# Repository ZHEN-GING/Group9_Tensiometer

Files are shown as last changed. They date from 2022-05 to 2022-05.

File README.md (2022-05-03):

# Group9_Tensiometer
 
1. We use TinkerCad to creat and edit a new clamp modeul, export to STL file so we could slice it with pursaSlice. Then , export it to SD card as G-code, so the 3d printer can print it directly. Here is our module: https://www.tinkercad.com/things/bVDQzztE6Tl-copy-of-surprising-amur-curcan/edit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 （need to log in）

2. System Parts: 
Steel gearing fit with servo motor(25T) ： https://www.amazon.com/dp/B07YWKMQ1M?ref=ppx_pop_mob_ap_share

LCD Screen： https://www.amazon.com/dp/B07S7PJYM6?ref=ppx_pop_mob_ap_share

ESP-12P： https://www.amazon.com/HiLetgo-Internet-Development-Wireless-Micropython/dp/B010O1G1ES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

  Servo Motor： https://www.amazon.com/dp/B07Z3VGZNP?ref=ppx_pop_mob_ap_share

3. 
For Arduino library:
<HX711.h>：https://github.com/bogde/HX711
<ESP8266WiFi.h> ：https://github.com/esp8266/Arduino/tree/master/libraries/ESP8266WiFi

For Blynk: https://www.youtube.com/watch?v=EYrEjC3QEew

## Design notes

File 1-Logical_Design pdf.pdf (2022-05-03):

PP-2017 V2.1

ANALYSIS & LOGICAL DESIGN | 1

# Logical Design Proposal Group Number 9

Gavin Haar, Liuhuan Zhang, Zhen Xu

Activity Report

Abstract—The paper “Fabrication of an Economical Arduino-based Uniaxial Tensile Tester” by Julien H. Arriza- balaga,† Aaron D. Simmons,‡ and Matthias U. Nollert et al. details how the team designed and constructed a tensiometer, which is a machine which measures the tensile strength of various materials, at a reduced cost compared to a professional model. Their model worked well, especially considering their low budget of only 100 dollars. However, their model has some shortcomings. Because the data collected before the improvement was not good. It has to do with the accuracy of the code, the accuracy of the components, the friction between the strings. Thus,the experiment will be improved in three ways – Improving System accuracy, Ease of use and Reduced setup time.

Index Terms—Uniaxial Tensiometer, System Analysis, Engineering Design

✦

### 1 BACKGROUND

D
Uring our initial testing, it became immediately apparent that the main issue with the original system is collecting consistent, repeatable, and accurate data. The first stress-strain curves that were generated using the system had very little coherence and, consequently, inhibited the calculation of important information such as ultimate tensile strength and Young’s modulus. As a team, we decided that improving the data collection stage is the single most important change that could be made to the system. Also, determining that the bulk of this issue comes from the method of applying force to the material. There are multiple design points that can be adjusted to improve this.
In order to satisfying the customers’ requirements. we are going to adjust and improve the accuracy and precision of measurement.
- Gavin Haar,
E-mail: ghaar@albany.edu,
- Liuhuan Zhang,
E-mail: lzhang21@albany.edu,
- Zhen Xu,
E-mail: zxu7@albany.edu,
University at Albany.

### 2 SYSTEM REQUIREMENTS & CON-

STRAINTS
Figure 1 depicts the system use cases diagram. In the original design, essentially, the prototype needed to be improved so that chemistry students could understand it and apply it to their experiments, such as testing the relationship between different materials. In this section, emphasizing Calibration and data collecting which are important. But there are several problems. First of all, we need to make a certain standard every steps of Calibration. Secondly, in terms of data collecting, artificial pulling of the rope led to incoherent data in the test data. This inconsistency has particularly hampered subsequent data analysis. The method of applying force needed to be changed. Also, the accuracy of the range sensor needs to be improved.

### 2.1 Make Calibration

Calibration is the beginning of the experiment and also affects the accuracy of the data collected later. So, there needs to be a standard for success.
calibration State Machine Figure 2 displays calibration State Machine.

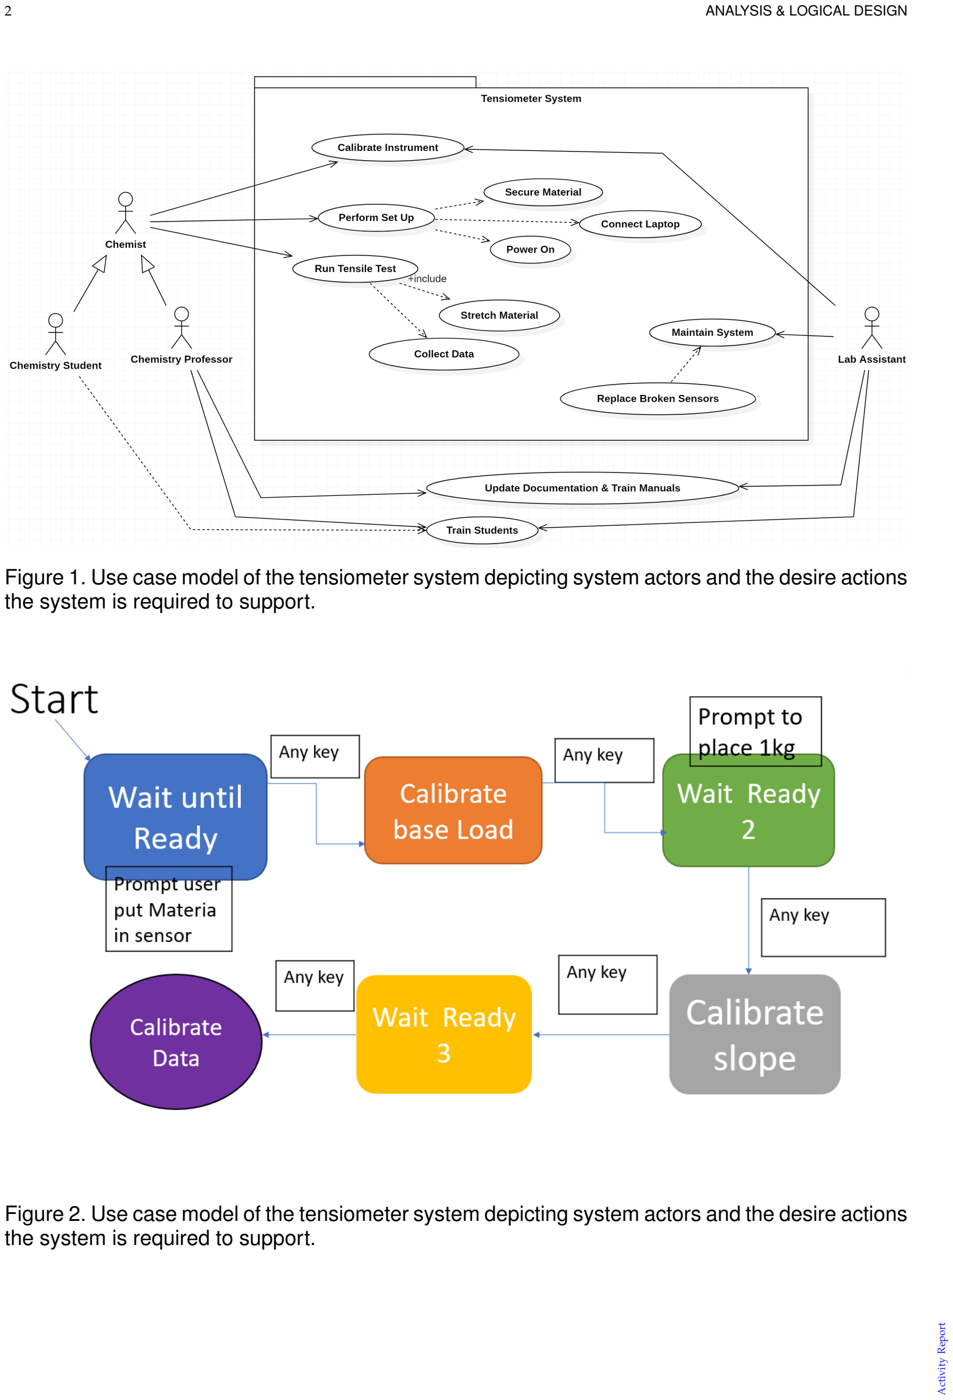
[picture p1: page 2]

Activity Report

2 | ANALYSIS & LOGICAL DESIGN

Figure 1. Use case model of the tensiometer system depicting system actors and the desire actions the system is required to support.

Figure 2. Use case model of the tensiometer system depicting system actors and the desire actions the system is required to support.

PP-2017 V2.1

SURNAME et al. | 3
- Step #1: Material is secured in the clamps
- Step #2: System prompts the user the
place the in tension and the press any
key
- Step #3: System records base load
- Step #4: System prompts user to place 1kg on the “bed” and then press any key (must should remain in tension)
- Step #5: System determines slope
- Step #6: System prompts the user to press any key to start collecting date
- Step #7: User should pull the rope very slowly

### 2.2 Requirement #2 improving data collec-

tion

In collecting the data, the data was very messy. The data may be irregular due to the uneven force caused by the experimental pulling the rope manually. In this case, the analysis and conclusions of material testing have a great impact. There’s a lot of uncertainty, because different people are pulling different numbers. This is a disastrous blow to the rigor of the experiment. So, some adjustments should be made to make the collected data look good. And, reduce more factors that affect the change of data. The goal, ultimately, is to be able to get other people to come to the same conclusion through the same process.
Implementing Force:
There are many issues with the method by which force is implemented. This was immediately apparent the first time that our team used the system. When pulling the rope by hand, first of all, it is difficult to pull constantly. It is necessary to add another component that allows for more constant application of force. Also, the ring at the top of the system that the rope goes through causes great amounts of friction. Improving these two areas will allow the test to run more smoothly, therefore improving the quality of data.
- Step #1: Replace with a better rope
- Step #2:Install pulley on top to decrease force of friction
- Step #3:Install a servo motor on top to pulls the rope

Improved Range Data:
Additionally, the quality of the data for the change in distance needs to be improved. The messiness of the stress-strain curve was also caused by inconsistencies in the distance data. This can be improved in a few different ways. Also, it becomes a hassle to account for the additional distance of the range sensor on top of the actual change in distance of the material, so this is another way that this can be improved.
- Step #1 Improve the code to reduce noisy by calculating average values of 20 numbers
- Step #2 Change a stronger clamp

### 2.3 Constraints

These constraints are typically imposed by the project sponsor, end user, or by external regulations. Constraints restrict the design process and limit the potential solutions. For this project, system constraints have already been defined and have been given to you below:
- Time Constraint: Completed and read to presentation/demonstrate by April 22nd
- Budget: Cost needs to be below $150. Going over budget will require strong justification as to the value added from the cost overrun.
- Replication: Relatively straight-forward process to replicate your work, such that building out a lab of identical tensiometers.
- Accessibility of Parts: Parts need to be readily accessible, ship quickly (not on back order) and available from common part suppliers (e.g., Digikey, Mouser, Adafruit, SparkFun, Amazon). Avoid parts that are difficult to source.
- Safety: System must be safe to operate without significant training or supervision Customer may want more accuracy to measure the distance and weight of data.

### 3 LOGICAL DESIGN

First install a Servo motor, and fixed at the top of the machine. By doing this, slowly pulling the string reduces the perceived error so that the collected data is not too cluttered. Second,

Activity Report

4 | ANALYSIS & LOGICAL DESIGN

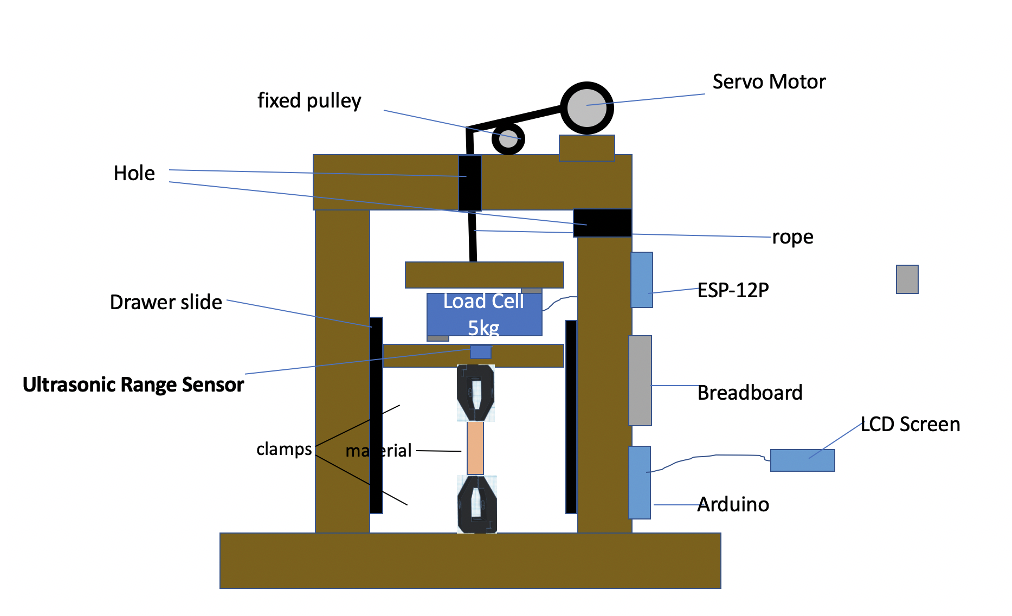
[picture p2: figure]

Figure 3. logical sketch of the current system

a pulley is installed at the top to reduce friction and improve the accuracy of data collection. Third, replace the rope with cable pulled by motor so that it stays stiff all the time. Reduce the impact of the rope’s elasticity. Fourth, improve the clarity of the stress-strain curve is to improve the code to reduce noisy by taking average values. Also, Matlab could help produce perfect graph, value of Young’s Modulus and value of Ultimate tensile Strength. Fifth, WIFI module could control servo motor with smartphone’s application—Blynk. It is interesting. sixth, stronger clamp printed by 3D printer. Seventh, a LCD Screen allows customers to see changes in visual data

### 3.1 Design Justification

Design principles extend the notion of design rationales that document how a design decision emerged. Extending the concept of design rationales by using theoretical hypotheses to support or object to design decisions. First, the link between theory and design decision enables the designer to reason about the resulting behavior of the project prior to instantiation. Second, design principles allow deducing empirically testable hypotheses to foster the rigorous evaluation of project. We all agree with that the height of Sonar sensor is largest misleading point. So we would measure and adjust the actually distance between sensor to target.

REFERENCES

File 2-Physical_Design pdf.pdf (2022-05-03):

PP-2017 V2.1

PHYSICAL DESIGN | 1

# Physical Design Proposal Number #9

Zhen Xu, Liuhuan Zhang, Gavin Haar

Activity Report

✦

### 1 PROPOSED SOLUTION

In the initial design there are multiple flawed aspects. Broadly speaking, these are components which prevent the user from consistently applying force to the material. A few examples are that the rope needs to be pulled by hand, and that there is a large amount of friction in the ring on top of the system. In summary, most of the improvement to the system will come from optimizing the method of applying force to the material. Thus,the experiment will be improved in three ways – Improving System accuracy, Ease of use and Reduced setup time. In terms of system accuracy, improving code to reduce noisy by acquiring average value, installing servo motor to reduce artificial error and changing stronger clamp to catch materials tightly. In terms of ease of use, Blynk could be used to control the motor rotating or rolling back even its speed which could collect more data. About reduced setup time, Arduino code could be used when calibrating the material. Also, Matlab could easily gets graph and its values of Young’s modulus and Ultimate tensile strength.

- Zhen Xu,
E-mail: zxu7@albany.edu,
- Liuhuan Zhang,
E-mail: lzhang21@albany.edu,
- Gavin Haar,
E-mail: ghaar@albany.edu,
University at Albany.

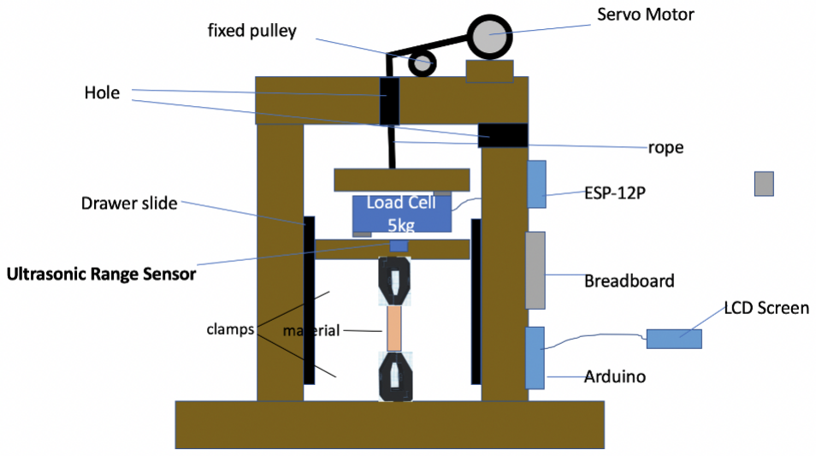
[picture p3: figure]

Figure 1. Current state of the tensiometer physical design

### 2 SYSTEM ARCHITECTURE

First install a Servo motor, and fixed at the top of the machine. By doing this, slowly pulling the string reduces the perceived error so that the collected data is not too cluttered. Second,a pulley is installed at the top to reduce friction and improve the accuracy of data collection. Third, replace the rope with cable pulled by motor so that it stays stiff all the time. Reduce the impact of the rope’s elasticity. Fourth, improve the clarity of the stress-strain curve is to improve the code to reduce noisy by taking average values. Also, Matlab could help produce perfect graph, value of Young’s Modulus and value of Ultimate tensile Strength. Fifth, WIFI module could control servo motor with smartphone’s application—Blynk. It is interesting. sixth, stronger clamp printed by 3D printer. Figure 2 depicts the current system circuitry with the load cell acting a wheatstone bridge

Activity Report

2 | PHYSICAL DESIGN

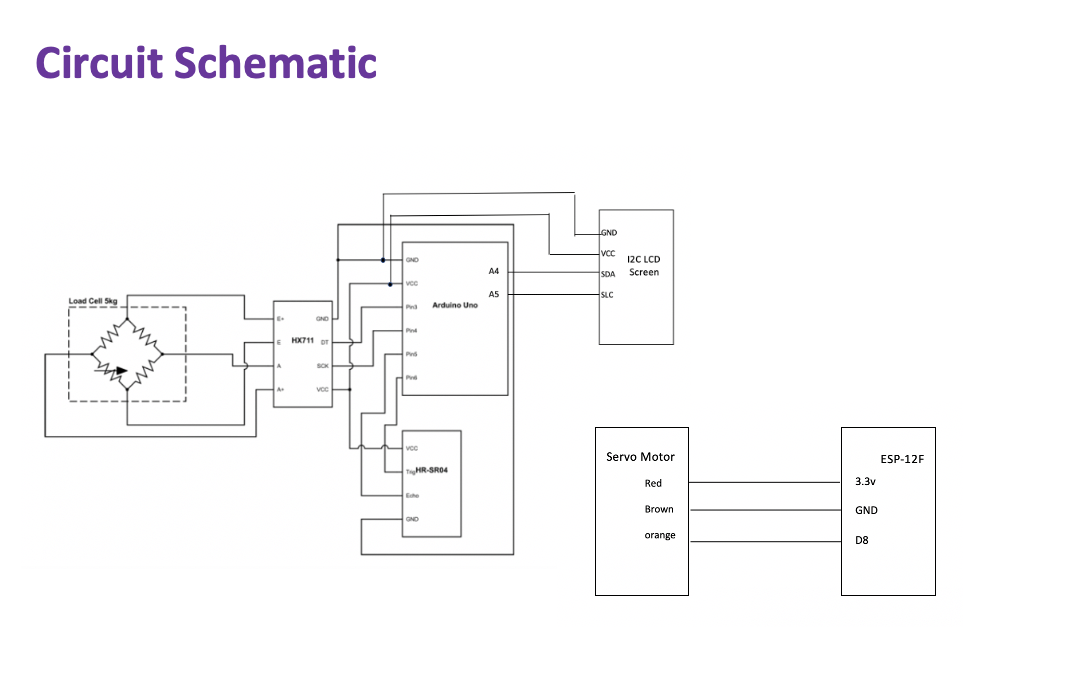
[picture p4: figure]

Figure 2. Schematic diagram of tensiometer electronics.

and the resulting output voltage amplified to the range of the ADC. The HX711 board and LCD Screen uses the amplifed value to perform a ADC conversion and then communicates the results using the I2C communication standard with the attached microcontroller. In the WIFI module, it is separate from the above system. ESP-12F connects to the motor’s signal, and Blynk could control the signal as to let motor rotate or rollback.
In terms of HX711, GND – GND(Arduino), VCC – VCC(Arduino), DT – Pin2(Arduino), SCK – Pin3(Arduino).
In | terms | of | LCD | Screen, | GND | –
GND(Arduino), VCC – VCC(Arduino), SDA – A4(Arduino), SLC – A5(Arduino).
In terms of HR-SR04, GND – GND(Arduino), VCC – VCC(Arduino), Echo – Pin4(Arduino), Trig – Pin5(Arduino).
In terms of ESP-12F, 3.3v – Red wire(Servo Motor), GND – Brown wire(Servo Motor), D8 – Orange wire(Servo Motor).

### 2.1 System Components

First, the installation of the servo motor avoids the error caused by pulling the rope manually. Because the motor can pull the rope at a constant speed and the speed of the motor can be controlled by Blynk so that more data can be obtained to ensure accuracy.
Second, we use a 3D printer to print the clamp which is stronger than original one so that could reduce error
Item | Part # | Cost
Rope | Cable | $9
LCD Screen | I2C | $5.5
WIFI module | ESP-12P | $9
Servo Motor | 30kg | $24
Others | Fixed pully and screw | $5.5
TOTAL | | $53.5
Table 1
overview cost of new parts

An example table summarizing the parts and budget is shown in Table 1.

2.1.1 Load Cell (5kg) / HX711 Amplifier
Load Cell could be used to measure the force exerting on the material.

2.1.2 Ultrasonic Range Sensor
And Ultrasonic Range Sensor could measure the distance between Sensor and the bottom

2.1.3 Rope
Reduce the impact of the rope’s elasticity.

2.1.4 Graphical Display
The current system uses the serial monitor to collect the data. If this changes, document the new methodology.

2.1.5 Laptop w/ Arduino Software
The current system requires use of a computer running the Arduino IDE to collect data from the serial monitor.

2.1.6 LCD Screen
Allows customers to see changes in visual data

2.1.7 Servo Motor
Avoid the error caused by pulling the rope manually.

2.1.8 ESP-12F
Control servo motor’s speed and its direction of rotation.

### 2.2 Engineering Standards

In the current system, there are two communication standards (protocols) that are utilized: I2C and UART, as shown in figure 3. Briefly describe how these work.

PP-2017 V2.1

SURNAME et al. | 3

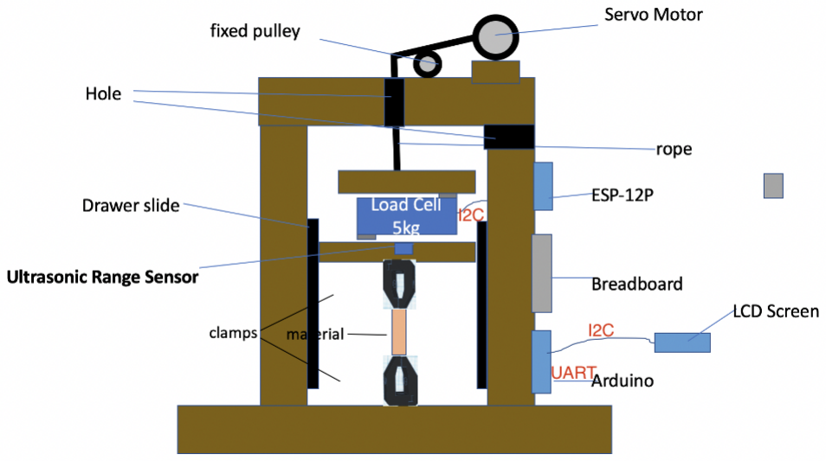
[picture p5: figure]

Figure 3. The current tensiometer system implements two communication standards (protocol) I2C and UART.

2.2.1 I2C Protocol
Inter-Integrated Circuit (pronounced eyesquared-C). It can supports multiple controllers and multiple peripherals

2.2.2 UART Protocol
A hardware communication protocol that uses asynchronous serial communication with configurable speed.

2.2.3 Data Standards
When getting data from Arduino monitor window, copy that and save it in an Excel file. Then, using Matlab, which is specifically designed, to get graph of Young’s Modulus.

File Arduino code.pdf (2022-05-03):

#include "HX711.h"

// CHANGE CALIBRATION CONDITIONS BASED ON BEST FIT LINE!!!
// For example, best fit equation is: y = mx + b. (where x is raw sensor value, y is the value in grams
double calibration_YIntercept = 272700; // TODO: Need to define best fit y intercept
double calibration_Slope = -432.7; // TODO: Need to define best fit slope //-----------------------------------------------------------------------------

// TODO: -Show connecting potentiometer to adjust Y_intercept
// | -Button to show slope
// | -Show state machines to support calibration steps

const double NEXT_WEIGHT = 0.1; // how much to weigh the next sample as part of the moving average
const int DELAY_MS = 10; //how many milliseconds between samples

const bool STRICTLY_INCREASING = true;

// HX711 circuit wiring
const int LOADCELL_DOUT_PIN = 4; const int LOADCELL_SCK_PIN = 5;

// Ultrasonic Range Sensor
const int ECHO_PIN = 2;
const int TRIG_PIN = 3;

double load, distance;
double prevDistance = 0.0;

typedef enum {START, WAIT_TILL_READY1, CALIBRATE_BASELINE, WAIT_TILL_READY2, CALIBRATE_1KG, WAIT_TILL_READY3, COLLECT_DATA, FINISHED} SystemState;
SystemState sysState = START;

int incomingByte = 0;

//Object representing load cell HX711 scale;
#include <LiquidCrystal_I2C.h> LiquidCrystal_I2C lcd(0x27,20,4);

void setup() {

//Define BAUD rate (Async. Communication Speed) Serial.begin(9600);

scale.begin(LOADCELL_DOUT_PIN, LOADCELL_SCK_PIN);

pinMode(TRIG_PIN, OUTPUT); // Sets the trigPin as an OUTPUT pinMode(ECHO_PIN, INPUT); // Sets the echoPin as an INPUT

//Display flie first row in CSV data standard (comma deliminator) //Serial.println("Distance (in cm), Load (in g), ");
lcd.init(); | // initialize the lcd
lcd.init();

}

void ticFunc(){
// Print a message to the LCD. lcd.backlight();

//State Transitions
switch(sysState){
case START:{
sysState = WAIT_TILL_READY1; break;
}
case WAIT_TILL_READY1:{
sysState = CALIBRATE_BASELINE; break;
}
case CALIBRATE_BASELINE:{
sysState = WAIT_TILL_READY2; break;
}
case WAIT_TILL_READY2:
sysState = CALIBRATE_1KG;
break;

case CALIBRATE_1KG:{
sysState = WAIT_TILL_READY3; break;
}
case WAIT_TILL_READY3:
sysState = COLLECT_DATA;
break;

}

//State Actions
switch(sysState){

case WAIT_TILL_READY1: {
Serial.println("CALIBRATE: PULL ROPE SLIGHTLY UNTIL MATERIAL IS BARELY IN TENSION");
lcd.setCursor(1,0);
lcd.print("PULL ROPE");
waitTillReady();

break;
}
case CALIBRATE_BASELINE:{
distance = getDistance();
load = getLoad();

// Baseline values
Serial.println("Calibrating.... Continue to hold material in place...."); lcd.setCursor(1,0);
lcd.print("Calibrating...");
lcd.setCursor(1,1);
lcd.print("Hold material");

for(int i=0;i<20;i++){
updateDistance();
updateLoad();
}
double baseDistance = distance; calibration_YIntercept = load;

Serial.print("ACCEPTED BASELINE VALUES: "); Serial.print("Load (raw): "); Serial.print(calibration_YIntercept); Serial.print(" , distance (cm): "); Serial.println(baseDistance); waitTillReady();

break;
}
case WAIT_TILL_READY2: {
Serial.println("CALIBRATE: CONTINUE KEEPING MATERIAL IN TENSION, PLACE 1kg ON BED");
lcd.setCursor(1,0);
lcd.print("PLACE 1kg.....");
lcd.setCursor(1,1);
lcd.print("Press key....."); waitTillReady();
break;
}
case CALIBRATE_1KG:{
load = getLoad();
distance = getDistance();
Serial.println("Calibrating.... Continue to hold material in place...."); for(int i=0;i<20;i++){
updateDistance();
updateLoad();
}
double deltaY = (load - calibration_YIntercept) ; double deltaX = 1000; //1kg
double slope = deltaY / deltaX; calibration_Slope = slope;
Serial.print("Load: ");
Serial.println(load);
Serial.print("Slope: ");
Serial.println(slope);
break;
}
case WAIT_TILL_READY3:{
Serial.println("Remove 1kg, then pull rope very slowly to start collecting stress-strain curve....");
lcd.setCursor(1,0);

lcd.print("Remove 1kg....."); lcd.setCursor(1,1);
lcd.print("Press key....."); waitTillReady();
break;
}
case COLLECT_DATA:{
load = getLoad();
distance = getDistance();
for(int i=0;i<10;i++){
updateDistance();
updateLoad();
}

if ( !STRICTLY_INCREASING || distance > prevDistance){
//x =(y-b) /m
double x = (load - calibration_YIntercept) / calibration_Slope; //Serial.print("Grams: ");
//Serial.println(x);
printVals();
prevDistance = distance;
}
break;
}

}

}

void loop() {

ticFunc();
delay(DELAY_MS);
}

void printVals(){
Serial.print(distance);
Serial.print("\t");
Serial.println( convertLoadToGrams(load) );

lcd.setCursor(1,0);
lcd.print("Distance: ");
lcd.print(distance);
lcd.setCursor(1,1);
lcd.print("Grams: ");
lcd.print(convertLoadToGrams(load)); }

//Rolling average of distance (10% weight for each new sample)
void updateDistance(){
double currDist = getDistance();
distance = ((1.0-NEXT_WEIGHT)*distance)+(NEXT_WEIGHT*currDist); }

//Returns the current distance of the ultrasonic range sensor double getDistance(){

digitalWrite(TRIG_PIN, LOW);
delayMicroseconds(2);

// Sets the trigPin HIGH (ACTIVE) for 10 microseconds digitalWrite(TRIG_PIN, HIGH);
delayMicroseconds(10);
digitalWrite(TRIG_PIN, LOW);

// Reads the echoPin, returns the sound wave travel time in microseconds double duration = pulseIn(ECHO_PIN, HIGH);

// Calculating the distance
double dist = (duration * 0.034) / 2.0; // Speed of sound wave divided by 2 (go and back)

return dist;
}

double updateLoad(){
double currLoad = getLoad();
load = ((1.0-NEXT_WEIGHT)*load)+(NEXT_WEIGHT*currLoad);

}

void waitTillReady(){
String str = "";
Serial.println("WHEN READY.... PRESS ANY KEY....");
while( str.equals("") ) {
str = Serial.readString();// read the incoming data as string //Serial.println(str);
}
}

double convertLoadToGrams(double l){
//x =(y-b) /m
double x = (load - calibration_YIntercept) / calibration_Slope; return x;
}

double getLoad(){
double avg = scale.read();

//double diff = avg - calibration_YIntercept;
//double grams = diff / calibration_Slope;

//y = mx + b (where y is the value in grams and x is the raw value) // double grams = (calibration_Slope)*avg + calibration_YIntercept;

return avg;
//return grams;
}

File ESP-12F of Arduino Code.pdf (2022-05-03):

#define BLYNK_PRINT Serial

#include <ESP8266WiFi.h>

#include <BlynkSimpleEsp8266.h>

#include <Servo.h>

Servo servo;

//Serial Number from Blynk
char auth[] = "1gTRMNMVK18cQDllwvhA_a7liPkpIp7z";

//Account of WIFI
char ssid[] = "Mi";
//Password of WIFI
char pass[] = "88888888";

void setup()

{

Serial.begin(9600);

Blynk.begin(auth, ssid, pass);

servo.attach(15); // NodeMCU D8 pin

}

void loop()

{

Blynk.run();

}

BLYNK_WRITE(V1)

{

servo.write(param.asInt());

}

BLYNK_WRITE(V2)

{

servo.write(0);

}

BLYNK_WRITE(V3)

{

servo.write(90);

}

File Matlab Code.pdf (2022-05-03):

clear
T = xlsread('data2.xlsx');

%Independent Variable
x = T(:, 1);

% Dependent Variable
y = T(:, 2);

%original distance
x1 = xlsread('data2.xlsx','Sheet1','A1:A1');

%Cross-sectional area
y1 = 0.01*76.2*(10^-6); %For Nitrile Gloves y11 = 0.013*127*(10^-6); %For Latex Gloves

%Strain
x2 = (x - x1)/11;

%Stress
y2 = (y*0.0098) / y11;

figure
plot(x2,y2,'-');
title('Stress VS Strain'); xlabel('Strain');
ylabel('Stress')

%ultimate Tensile Strenth
y3 = max(y2);

%For Youngâ€™s Modulus
x4 = xlsread('data2.xlsx','Sheet1','A2:A5'); y4 = xlsread('data2.xlsx','Sheet1','B2:B5');

x5 = (x4 - x1)/1;
y5 = (y4*0.0098) / y11;

p = polyfit(x5,y5,1);

fprintf("Youngâ€™s Modulus: "); display(p);
fprintf("Ultimate Tensile Strenth "); display(y3);

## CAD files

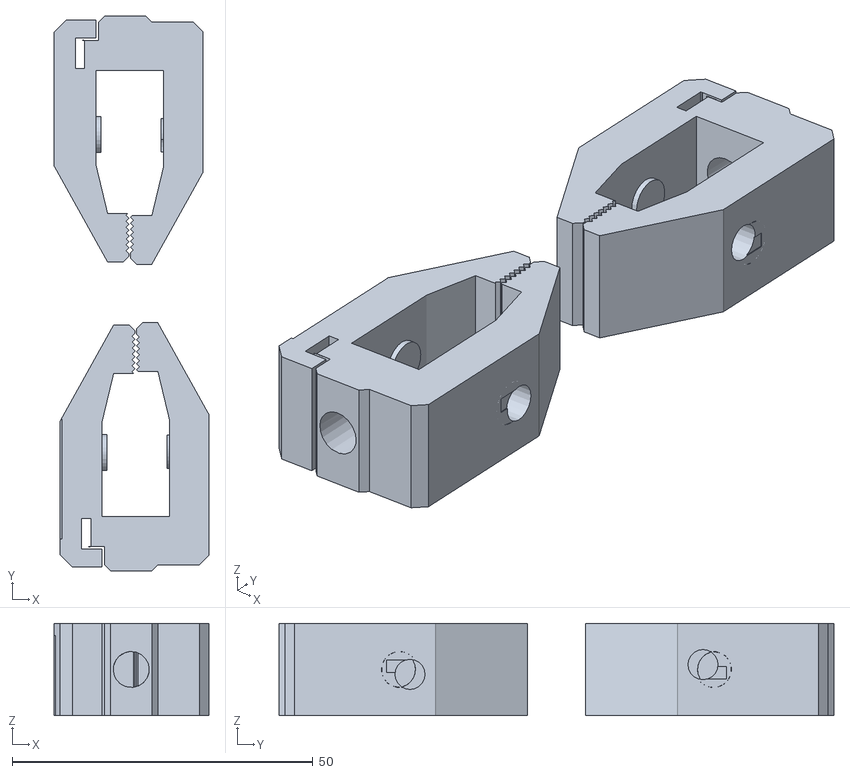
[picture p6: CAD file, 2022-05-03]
3D model --Clamp.stl
25.8 x 92.3 x 15.4

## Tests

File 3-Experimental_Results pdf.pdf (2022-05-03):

PP-2017 V2.1

EXPERIMENTAL DESIGN | 1

# Project Milestone 4 Experimental Results

Gavin Haar, Zhen Xu, Liuhuan Zhang

Activity Report

✦

### 1 RESEARCH QUESTION

Our upgraded uniaxial tensiometer system improves system accuracy by using a reliable motor to stretch the material and implementing more advanced code. Additionally, our system improves the user’s experience by interfacing through a phone app. To demonstrate these improvements, the system was tested on latex and nitrile material. The resulting data was compared to known values for each material.

### 2 EXPERIMENTAL RESULTS

To test each material, a stress strain curve was constructed using the distance and the force data collected. These graphs, included in figure 1 and figure 2, show the amount of stress on a material that causes it to stretch and eventually break. Numerous data points can be collected from these graphs, including young’s modulus and ultimate tensile strength, which are included in table 1. Young’s modulus is the slope of the curve in the initial linear region, and ultimate tensile strength is the maximum strain that a material can endure before breaking.

### 3 DATA ANALYSIS

As can be seen from these results, the system is a great improvement from our initial testing.

- Gavin Haar. 12222,
E-mail: ghaar@albany.edu,
- Zhen Xu. 12222,
E-mail: zxu7@albany.edu,
Electrical & Computer Engineering, University at Albany.

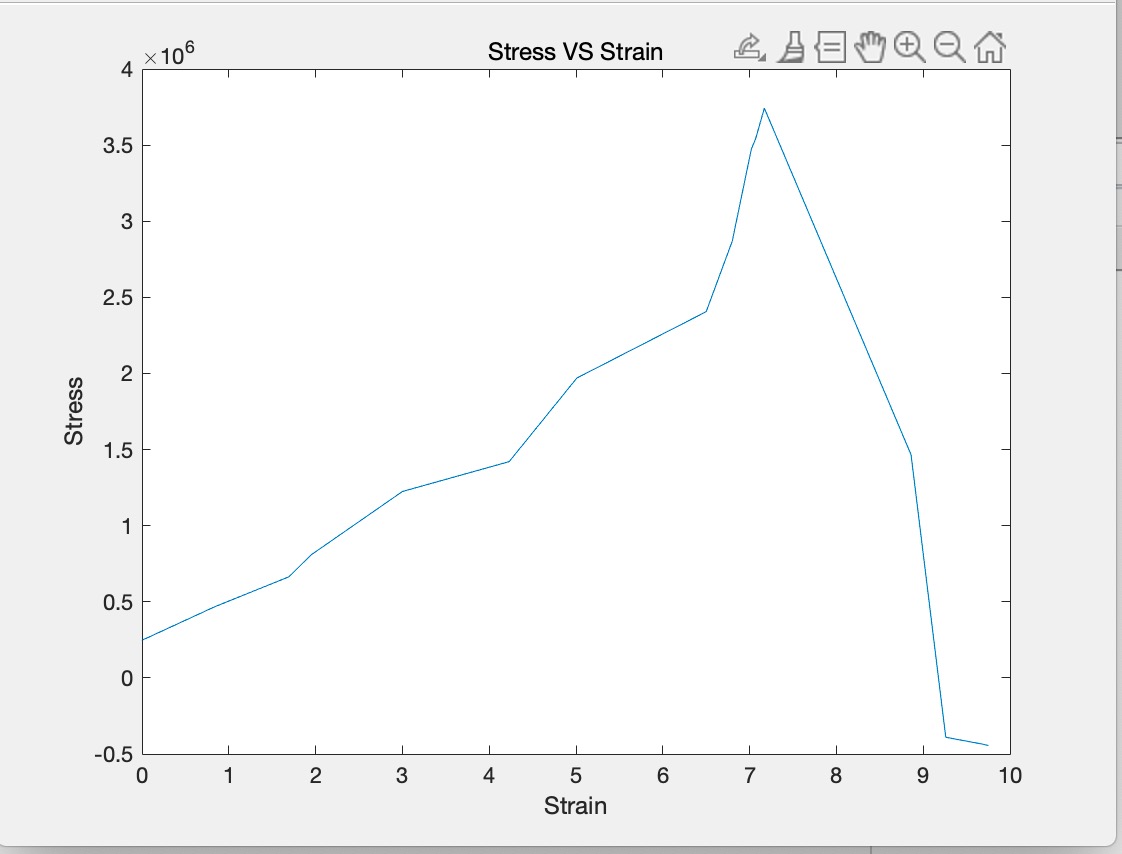
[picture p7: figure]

Figure 1. Stress-strain curve derived from our system for Latex glove sample

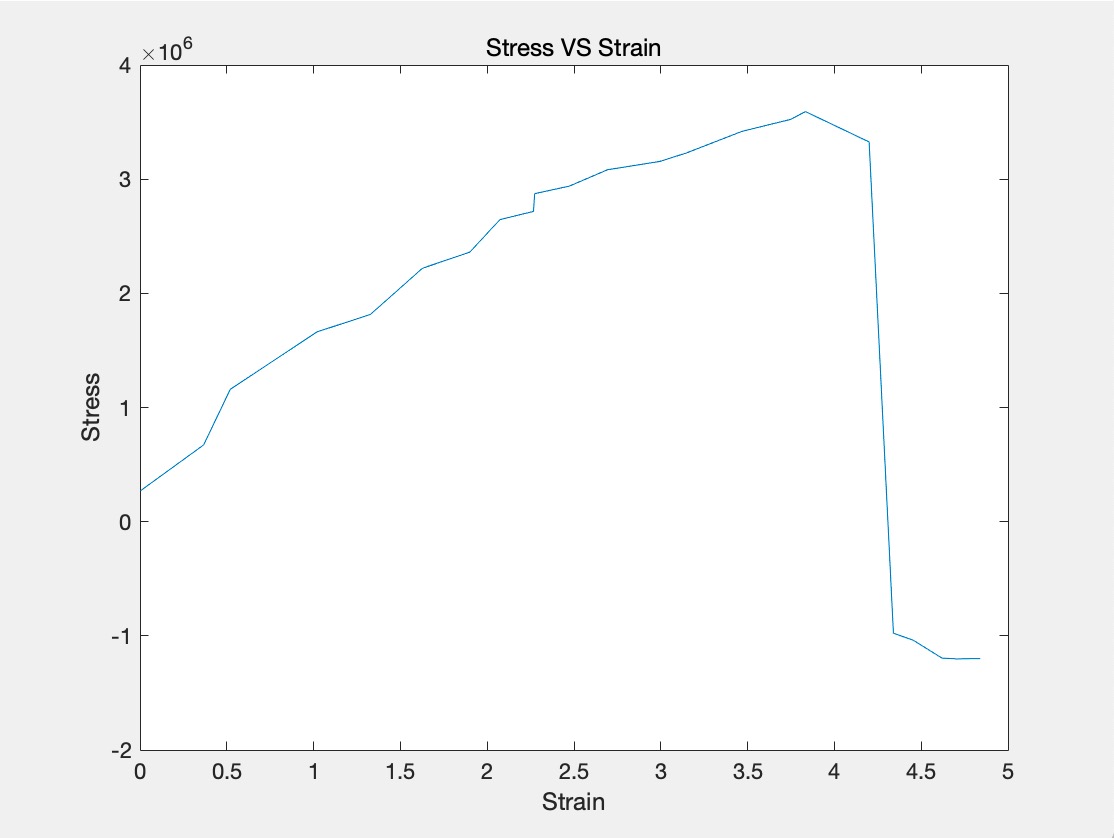
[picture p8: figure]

Figure 2. Stress-strain curve derived from our system for nitrile glove sample

Activity Report

2 | EXPERIMENTAL DESIGN
Metric | Sample | # Trials | Our System | Known Value | Error
Young’s Modulus | Latex Glove | 1 | 864 kPa | 740 ± 10 kPa | 16.8
.. | Nitrile Glove | 1 | 2.03 MPa | 2.4 ± 0.2 MPa | 15.3
Ultimate Tensile Strength | Latex Glove | 1 | 3.74 MPa | 3.3 ± 0.1 MPa | 13.3
.. | Nitrile Glove | 1 | 3.80 MPa | 4.4 ± 0.1 MPa | 13.6
Table 1
Summary of experimental results

Now, the system is producing curves in the recognizable shape of a stress-strain curve with much improved accuracy. The code which we implemented offered a ’smoothing’ effect on the curve and made up for error in the sensors which were used. Additionally, the phone app interface and installed motor definitely improved the ease of use. This is an aspect of the system which was very impressive and worked very well. The system could be improved further to get young’s modulus and ultimate tensile strength within 10 percent of known values, however it is a vast improvement from the original system.
